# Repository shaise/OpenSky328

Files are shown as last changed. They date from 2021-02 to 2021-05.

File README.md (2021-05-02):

# OpenSky328
An atmel implementation of OpenSky FrSky-compatible RX  
Based on https://github.com/fishpepper/OpenSky

## Description
This open project aims to develop a family of small rc receivers compatibe with FR-Sky with telemetry.
List of devices:
* FR-8: An 8 channel PWM receiver with 2 analog telemetry inputs.
* FR-Tiny: A 5 channel micro receiver with brushed motor ESC, for micro rc planes. Weights just 2 grams.
* FR-LVH: A 1S land vehicle version with 2 bidirectional brushed motor esc (ch:1,2) and 2 servos (ch:3,4).
* Programmer adapter: Lets you connect above devices to a USBASP programmer, and USB-SERIAL adapter
The hardware is based on Atmega 328p microcontroller and TI CC2500 transceiver. 
The firmware is based on OpenSky FrSky-compatible receiver: https://github.com/fishpepper/OpenSky
It is also arduino based.

## 1. FR-8
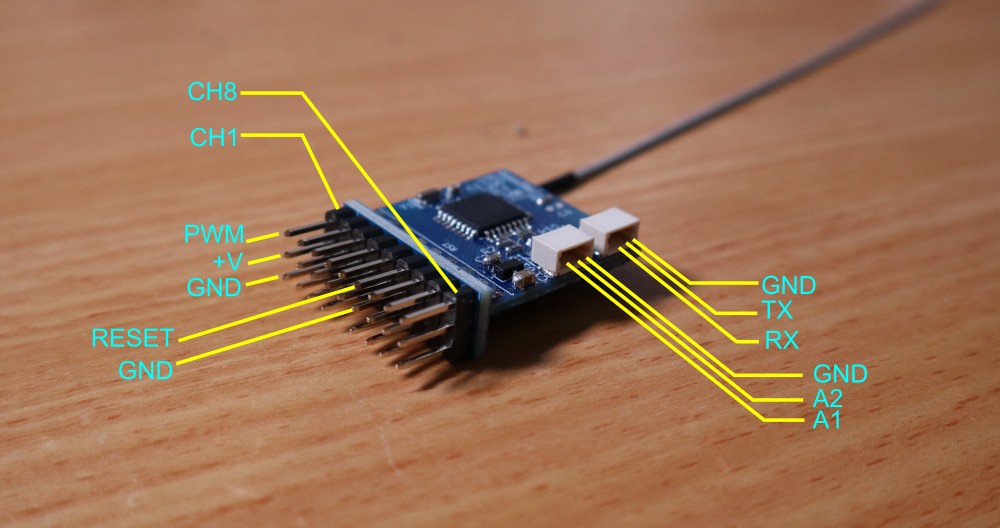
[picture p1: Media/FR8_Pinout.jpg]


## 2. FR-Tiny
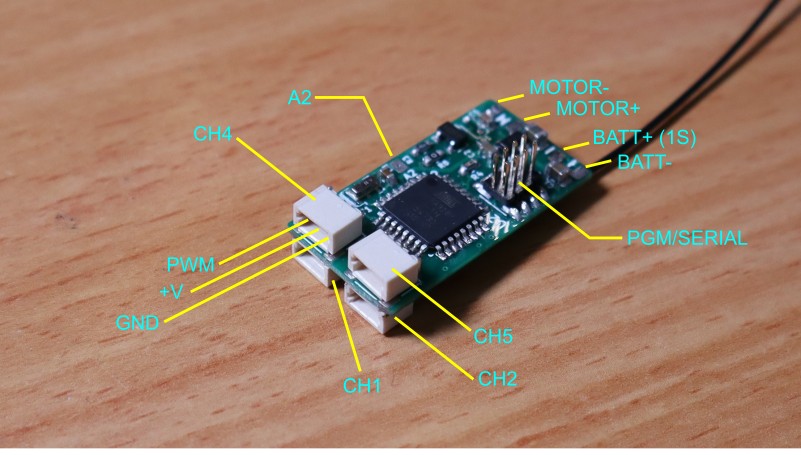
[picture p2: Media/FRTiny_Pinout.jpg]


## 3. FR-LVH
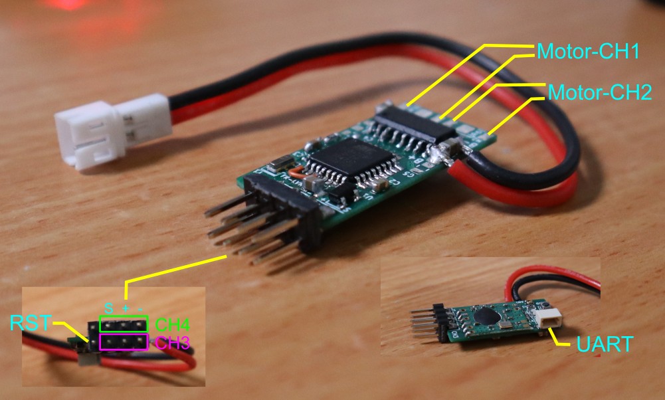
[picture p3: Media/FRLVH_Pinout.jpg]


## 4. FR-Pgm programmer
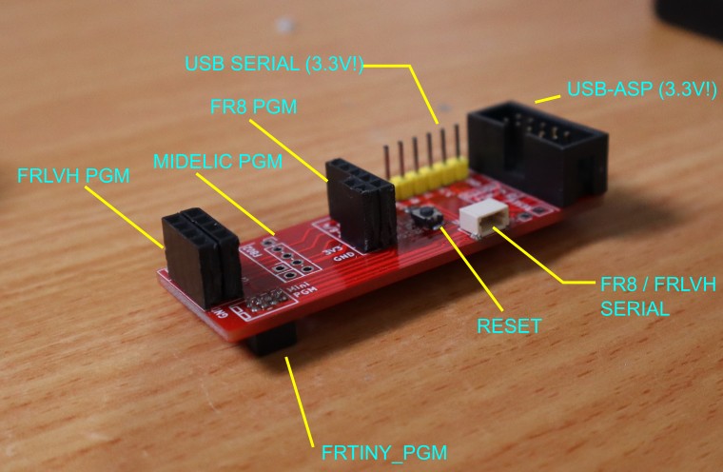
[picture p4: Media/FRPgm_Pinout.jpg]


## Assembling instructions

* Order the PCB by sending the gerbrt files to a manufacturer of your choice. I recommend [JLCPCB](https://jlcpcb.com/).
  * [FR-8 gerber files](/Release/gerbers_fr8_V1_2Layer_FR4_1.6mm.zip) and [FR-8 pins gerber files](/Release/gerbers_frmini8_pins_V1_2Layer_FR4_1.6mm.zip)
  * [FR-Tiny](/Release/gerbers_frtiny_V5_4Layer_FR4_1.0mm.zip)
  * [FR-LVH](/Release/gerbers_frlvh_V2_SWPWM_4Layer_FR4_1.0mm.zip)
  * [FR-Pgm](/Release/gerbers_frmini_prog_V4_2Layer_FR4_1.6mm.zip)
* Order all parts as listed in the BOM file. You will need a 0603 kit of resistors and capacitors, and for all other parts you will find a link in the BOM.
  * [FR-8 BOM](/Release/FR8_bom.pdf)
  * [FR-Tiny BOM](/Release/FRTiny.pdf)
  * [FR-LVH BOM](/Release/FRLVH_bom.pdf)
  * [FR-Pgm BOM](/Release/FRReceiverProg.pdf)
* Solder all parts. You can use the interactive BOM to assist you.
  * [FR-8 Interactive BOM](https://htmlpreview.github.io/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)
  * [FR-Tiny Interactive BOM](https://htmlpreview.github.io/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)
  * [FR-LVH Interactive BOM](https://htmlpreview.github.io/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)
  * [FR-Pgm Interactive BOM](https://htmlpreview.github.io/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)

 ## Programming the firmware
* Clone or download this repository.
* Edit config.h file and set the correct PCB version by uncommenting the correct line:  

Comment | Board support  
--- | ---  
#define RXBOARD_FR8_FRTINY | FR-8 or FR-Tiny boards  
#define RXBOARD_FRLVH | FR-LVH land vehicle boards  
* You will need a USBASB compatible programmer and either the programmin adapter above (recomended) or connect your own wires.
* NOTE!!! USBASP must be 3.3V version or you risk damaging the receiver.
* The software is arduino compatible (Arduino nano), so it should work with the Arduino IDE, however I did not test that. Instead I recommend using the [VS Studio Code IDE](https://code.visualstudio.com). You will need to install the C/C++ Addon, and the Platform IO addon (from the addon menu). Within Platform IO install the Atmel AVR platform.
* Connect the built receiver to the programmer using the adapter as follows:  
For FR-8:  
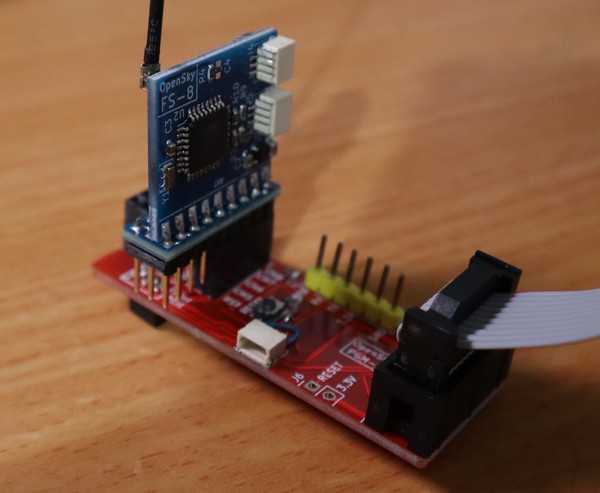
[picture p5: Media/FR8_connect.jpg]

  
For FR-Tiny:  
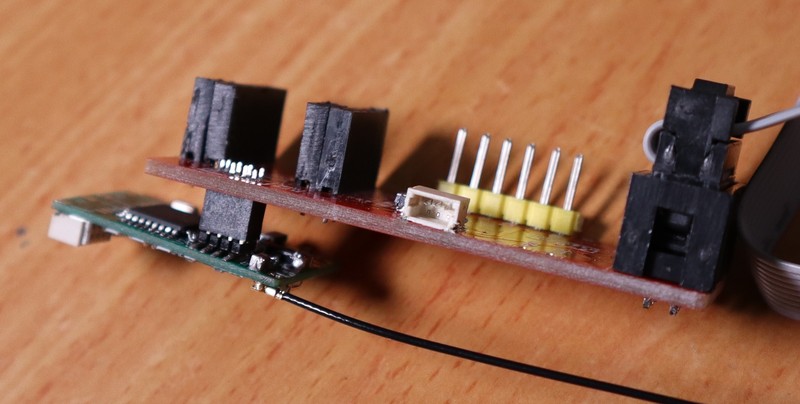
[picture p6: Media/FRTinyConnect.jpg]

  
For FR-LVH:  
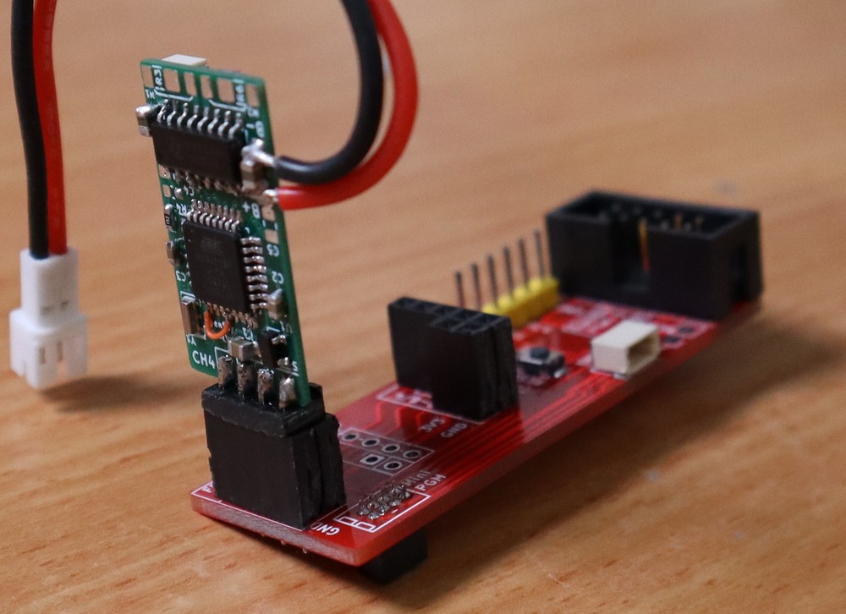
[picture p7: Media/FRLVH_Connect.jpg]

  
* Now open the 'Software' folder within VS Code. If you get a mesage that a workspace was detected, go ahead and press the "open workspace" button.
* On the left, click the PlatformIO icon (bug head), and from the "Project Tasks" menu, click the "Set fuses" line (should be under nanoatmega328->Platform). If everything is connected correctly, the Microcontroller fuses will be programmed.
* Now just press the 'PlatformIO: Upload" button at the bottom (the right arrow) and thats it!

## Usage
These receivers works with FR-Sky telemetry compatible transmitters (D8). (SW 1 and 2 off on DJT modules)
### Binding
You first need to bind the receiver with the transmitter (this is a one-time operation, repeat only if you change transmitter):  
* Press and hold the bind button and then powerup the receiver. Wait for the green light to turn on.
* Start binding procedure in your transmitter. If you are using an external module such as the DJT, Press and hold the module bind button and turn on the transmitter. 
* Wait for the red led on the receiver to start blinking. When it does, binding is complete! Turn off the transmitter and remove the receiver battery.
### Setting Fail safe
turn the tranmitter on then the receiver. Wait for the receiver green light to turn on. Press and hold the Bind button on the receiver for about 5 seconds till the red led turn on. Release the button, the red led will start blinking. You now have 10 seconds to set your fail safe state using the transmitter. When the time is up, the receiver will lock this state as the failsafe mode, and restart. when the green light is on again (without the red) the process is complete. This method of setting the fail safe mode is better then the standard, since you have both hands free to move the sticks to the desired state.
### Serial debugging
If you want to debug the receiver operation, you can use a serial terminal (built in VS code) to observe the debug data sent from the receiver.  
* Use a USB to serial Adapter. If you want to use the USB-serial to power the module, Make sure its a 3.3V version, or you risk damaging the modules.
* Connect the USB-Serial adapter to the programming adapter using the marked pins.
* Connect the programming adapter to the module as explained in the programming section.
* For the FR-Tiny you are all set. For the FR-8 / FR-LVH you will need an extra cable (jst to jst 1.0 mm 3pin) to connect the module to the serial input:  
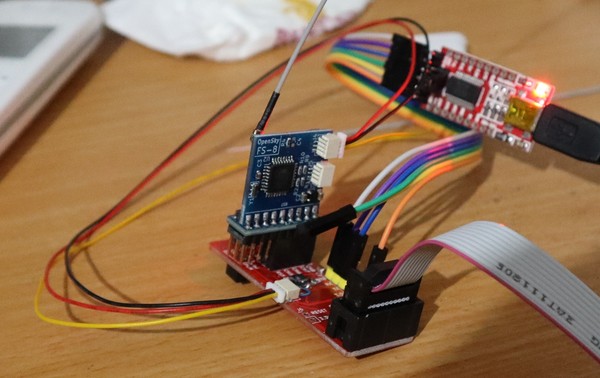
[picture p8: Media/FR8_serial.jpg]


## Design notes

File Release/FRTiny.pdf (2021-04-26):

Sheet1

Page 1

| Qty | References | Value | Footprint | Sourced
1 | 2 C3, C5 | | 100n_0603 | C_0603
2 | 1 C2 | | 22u_0603 | C_0603
3 | 1 C1 | | 4u7_0805_16V | C_0805
4 | 1 C4 | | 47u_0805 | C_0805
5 | 3 R2, R8, R10 | | 5K_0603 | R_0603
6 | 3 R4, R5, R7 | | 1K_0603 | R_0603
7 | 2 R1, R9 | | 22K_0603 | R_0603
8 | 1 R3 | | 0R_0603 | R_0603
9 | 1 D2 | | GREEN | LED_0603 | https://www.aliexpress.com/item/593098807.html
10 | 1 D3 | | RED | LED_0603 | https://www.aliexpress.com/item/593098807.html
11 | 1 U3 | | CC2500_MOD6 | CC2500_MOD6 | Std module: https://www.aliexpress.com/item/32246990983.html
12 | 1 U2 | | ATmega328P-MU | LQFP-32_7x7mm_P0.8mm | https://www.aliexpress.com/item/32213838233.html
13 | 1 U1 | | MCP1700 | SOT-23 | https://www.aliexpress.com/item/32995491794.html
14 | 1 Y1 | | CSTE16M | Res_SMD_3.0x1.3mm | https://www.aliexpress.com/item/2035036982.html
15 | 1 SW1 | | SW_BIND | SW_SPST_B3U-1000P | https://www.aliexpress.com/item/32623923874.html
16 | 1 AE1 | | Antenna_Shield | Conn_IPEX4 | https://www.aliexpress.com/item/10000166852637.html
17 | 1 Q1 | | Q_NMOS_GSD | SOT-23 | https://www.aliexpress.com/item/32983842840.html
18 | 4 J4, J5, J6, J7 | | JST1.0 | JST_SH_SM03B-SRSS-TB_1x03-1MP_P1.00mm_Horizont al | https://www.aliexpress.com/item/32819231540.html
19 | 1 J3 | | Conn_02x04_1.27 | PinHeader_2x04_P1.27m m_Vertical_SMD | https://www.aliexpress.com/item/4001224515002.html

None Pcb parts:
IPEX 4 antenna: | https://www.aliexpress.com/item/32990042506.html

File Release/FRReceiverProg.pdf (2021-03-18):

Sheet1

Page 1

| Qty | References | Value | Footprint | Sourced
1 | 2 | C1, C2 | 100n_0603 | C_0603_1608Metric
2 | 1 | SW1 | SW_Push | SW_SPST_4x3 | https://www.aliexpress.com/item/1005001412157463.html
3 | 1 | J3 | Conn_02x05 | IDC-Header_2x05_P2.54mm_Vertical | https://www.aliexpress.com/item/868008295.html
4 | 1 | J7 | Conn_01x03 | JST_SH_SM03B-SRSS-TB_1x03-1MP_P1.00mm_Horizontal | https://www.aliexpress.com/item/32819231540.html
5 | 1 | J6 | Conn_01x02 | PinHeader_1x02_P2.54mm_Vertical | cut to length https://www.aliexpress.com/item/32993182990.html
6 | 1 | J5 | Conn_01x06 | PinHeader_1x06_P2.54mm_Vertical | cut to length https://www.aliexpress.com/item/32993182990.html
7 | 2 | J4, J9 | Conn_01x02 | PinSocket_1x02_P2.54mm_Vertical | https://www.aliexpress.com/item/32863474581.html
8 | 2 | J1, J8 | Conn_01x05 | PinSocket_1x05_P2.54mm_Vertical | https://www.aliexpress.com/item/32667248348.html
9 | 1 | J2 | Conn_02x04 | PinSocket_2x04_P1.27mm_Vertical | https://www.aliexpress.com/item/4000960160661.html

Non PCB parts:
USB Serial adaprer: | Set to 3.3V! | https://www.aliexpress.com/item/33037470874.html
USBASP programmer: | Set to 3.3V! | https://www.aliexpress.com/item/32647598702.html
Serial jumper cable: | Select 3 pin double head | https://www.aliexpress.com/item/1005001303141070.html

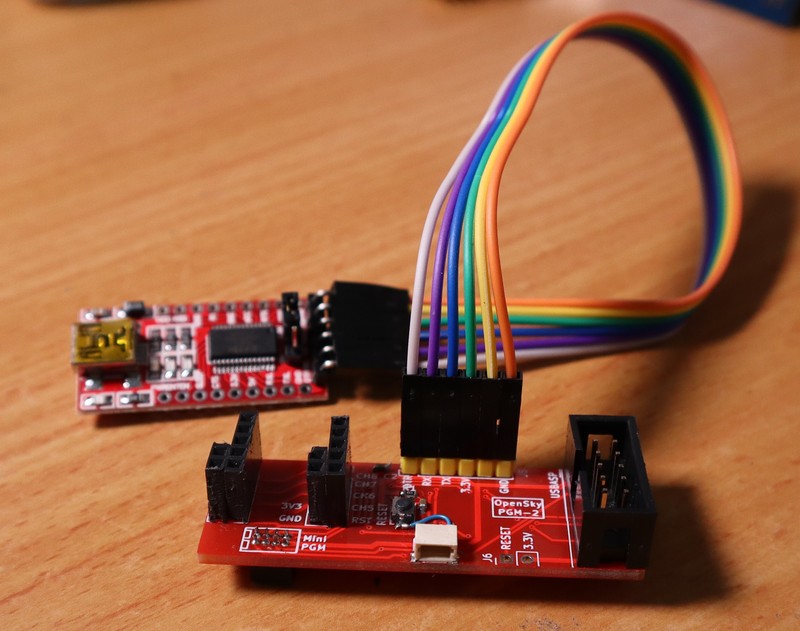
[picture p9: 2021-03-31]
Media/FRPgm_Serial.jpg

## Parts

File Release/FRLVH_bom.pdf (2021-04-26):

Sheet1

1 | 1 C2 | 22u_0603 | C_0603_1608Metric
2 | 1 C3 | 100n_0603 | C_0603_1608Metric
3 | 1 C4 | dns_0603 | C_0603_1608Metric
4 | 4 C5, C6, C7, C8 | 47u_0805 | C_0805_2012Metric
5 | 1 C1 | 4u7_0805_16V | C_0805_2012Metric
6 | 3 R4, R5, R7 | 1K_0603 | R_0603_1608Metric
7 | 1 R1 | 22K_0603 | R_0603_1608Metric
8 | 1 R2 | 5K_0603 | R_0603_1608Metric
9 | 2 R3, R6 | 10R_2512 | R_1206_3216Metric
10 | 1 D2 | GREEN | LED_0603_1608Metric
11 | 1 D3 | RED | LED_0603_1608Metric
12 | 1 U3 | CC2500_MOD6 | CC2500_MOD6
13 | 1 U4 | MX1508/MX1616 | SOIC-16
14 | 1 U1 | MCP1700 | SOT-23
15 | 1 U2 | ATmega328P-AU | TQFP-32_7x7mm_P0.8mm
16 | 1 Y1 | CSTE16M | Resonator_SMD_3.0x1.3mm
17 | 1 SW1 | SW_BIND | SW_SPST_B3U-1000P
18 | 1 AE1 | Antenna_Shield | Conn_IPEX4
26 | 1 J4 | JST1.0 | JST_SH_1x03- 1MP_P1.00mm_Horizontal

Sheet1

https://www.aliexpress.com/item/593098807.htmlhttps://www.aliexpress.com/item/593098807.html

https://www.aliexpress.com/item/4000426470690.htmlhttps://www.aliexpress.com/item/32995491794.htmlhttps://www.aliexpress.com/item/32213838233.htmlhttps://www.aliexpr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

https://www.aliexpress.com/item/32819231540.html

Std module: https://www.aliexpress.com/item/32246990983.html

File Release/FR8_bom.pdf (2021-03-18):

Sheet1

Page 1

| Quantity | References | Value | Footprint | Sourced
1 | 1 C2 | | 22u_0603 | C_0603
2 | 1 C3 | | 100n_0603 | C_0603
3 | 1 C4 | | dns_0603 | C_0603
4 | 1 C1 | | 4u7_0805_16V | C_0805
5 | 3 R4, R5, R7 | | 1K_0603 | R_0603
6 | 2 R1, R9 | | 22K_0603 | R_0603
7 | 2 R2, R10 | | 5K_0603 | R_0603
8 | 1 D2 | | GREEN | LED_0603 | https://www.aliexpress.com/item/593098807.html
9 | 1 D3 | | RED | LED_0603 | https://www.aliexpress.com/item/593098807.html
10 | 1 U3 | | CC2500_MOD6 | CC2500_MOD6 | Std module: https://www.aliexpress.com/item/32246990983.html
11 | 1 U4 | | CC2500_MOD6_PA | CC2500_MOD6_PA | Long range module: https://www.aliexpress.com/item/32810257490.html
12 | 1 U1 | | MCP1700 | SOT-23 | https://www.aliexpress.com/item/32995491794.html
13 | 1 U2 | | ATmega328P-AU | TQFP-32_7x7mm_P0.8mm | https://www.aliexpress.com/item/32213838233.html
14 | 1 Y1 | | CSTE16M | Res_SMD_3.0x1.3mm | https://www.aliexpress.com/item/2035036982.html
15 | 1 SW1 | | SW_BIND | SW_SPST_4x3 | https://www.aliexpress.com/item/1005001412157463.html
16 | 2 AE1, AE2 | | Antenna_Shield | U.FL_Hirose_U.FL-R-SMT-1_Vertical | https://www.aliexpress.com/item/33059352910.html
18 | 2 J4, J5 | | JST1.0 3pin | JST_SH_SM03B-SRSS-TB_1x03-1MP_P1.00mm_Horizon tal | https://www.aliexpress.com/item/32819231540.html

None PCB parts:
Ufl IPEX1 antenna: | https://www.aliexpress.com/item/4000290422103.html

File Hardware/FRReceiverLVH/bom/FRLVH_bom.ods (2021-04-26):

1 | 1 | C2 | 22u_0603 | C_0603_1608Metric
2 | 1 | C3 | 100n_0603 | C_0603_1608Metric
3 | 1 | C4 | dns_0603 | C_0603_1608Metric
4 | 4 | C5, C6, C7, C8 | 47u_0805 | C_0805_2012Metric
5 | 1 | C1 | 4u7_0805_16V | C_0805_2012Metric
6 | 3 | R4, R5, R7 | 1K_0603 | R_0603_1608Metric
7 | 1 | R1 | 22K_0603 | R_0603_1608Metric
8 | 1 | R2 | 5K_0603 | R_0603_1608Metric
9 | 2 | R3, R6 | 10R_2512 | R_1206_3216Metric
10 | 1 | D2 | GREEN | LED_0603_1608Metric | https://www.aliexpress.com/item/593098807.html
11 | 1 | D3 | RED | LED_0603_1608Metric | https://www.aliexpress.com/item/593098807.html
12 | 1 | U3 | CC2500_MOD6 | CC2500_MOD6 | Std module: https://www.aliexpress.com/item/32246990983.html
13 | 1 | U4 | MX1508/MX1616 | SOIC-16 | https://www.aliexpress.com/item/4000426470690.html
14 | 1 | U1 | MCP1700 | SOT-23 | https://www.aliexpress.com/item/32995491794.html
15 | 1 | U2 | ATmega328P-AU | TQFP-32_7x7mm_P0.8mm | https://www.aliexpress.com/item/32213838233.html
16 | 1 | Y1 | CSTE16M | Resonator_SMD_3.0x1.3mm | https://www.aliexpress.com/item/2035036982.html
17 | 1 | SW1 | SW_BIND | SW_SPST_B3U-1000P | https://www.aliexpress.com/item/32623923874.html
18 | 1 | AE1 | Antenna_Shield | Conn_IPEX4 | https://www.aliexpress.com/item/10000166852637.html
26 | 1 | J4 | JST1.0 | JST_SH_1x03-1MP_P1.00mm_Horizontal | https://www.aliexpress.com/item/32819231540.html

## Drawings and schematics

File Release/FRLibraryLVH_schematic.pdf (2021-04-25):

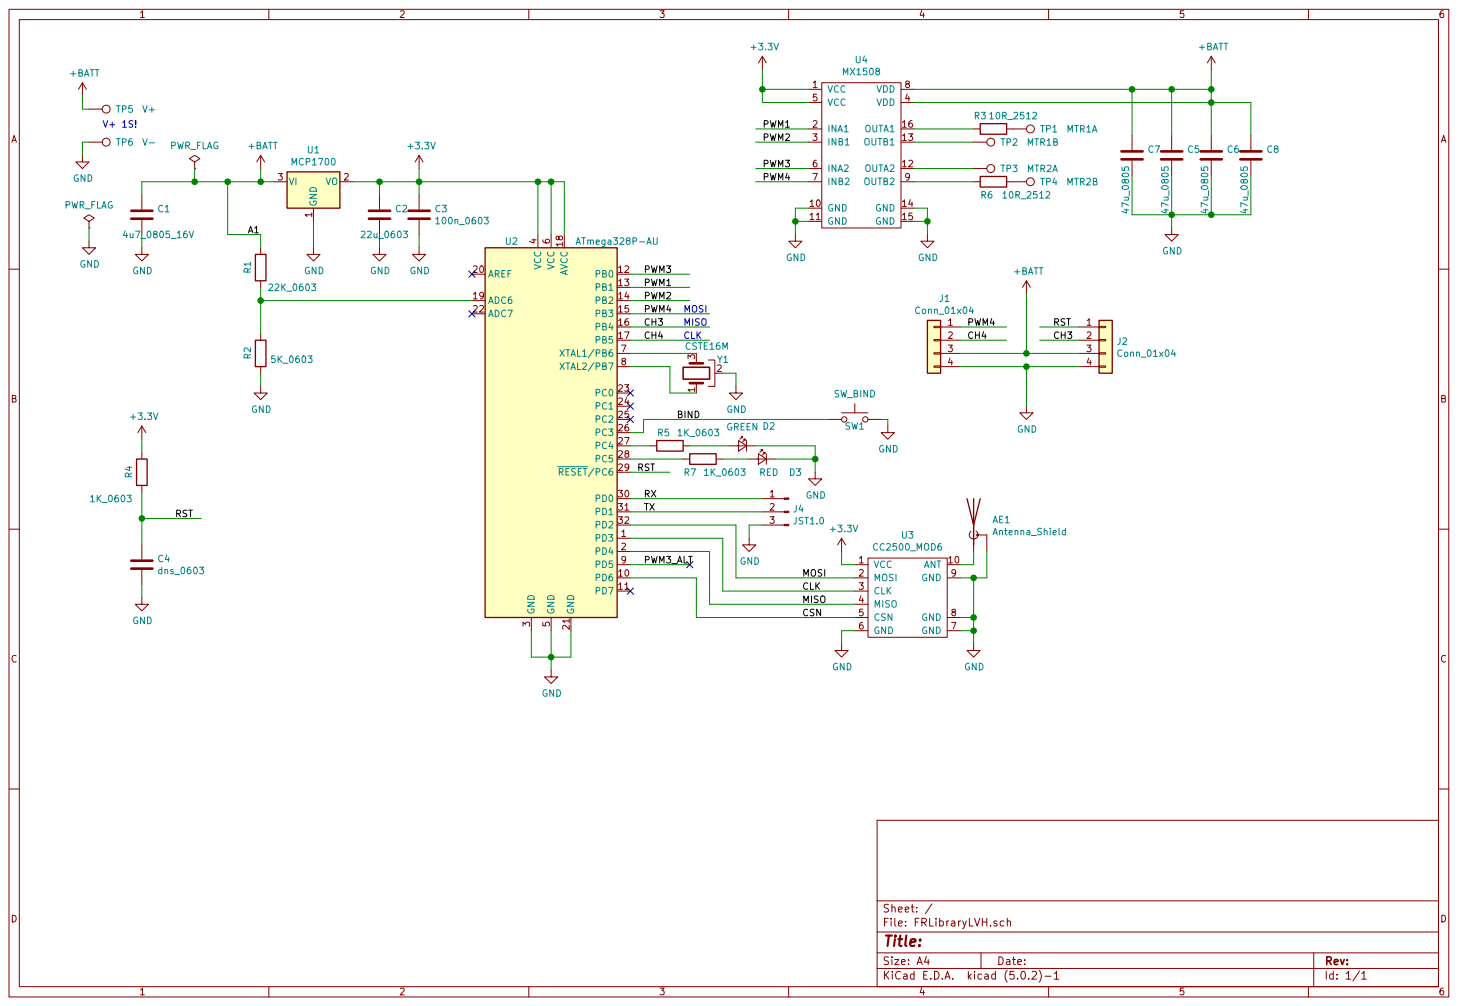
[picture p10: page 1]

1 VO 2 VI 3 U1 MCP1700 PD3 1 PD6 10 PD7 11 PB0 12 PB1 13 PB2 14 PB3 15 PB4 16 PB5 17 AVCC 18 ADC6 19 PD4 2 AREF 20 GND 21 ADC7 22 PC0 23 PC1 24 PC2 25 PC3 26 PC4 27 PC5 28 RESET/PC6 29 GND

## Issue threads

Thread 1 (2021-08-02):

Planning to make one but problem sourcing components.

saintofinternet, 2021-08-02:
Hello,

I am planning to make this as per your instructions but I am finding it difficult to source the components as per your list in Bill of Material.

What alternative do I have to carry out this work?

Regards,
-Siddharth

shaise, 2021-08-02:
Hi,

Please let me know which of the parts you can not find, and I will try to find another sorce.

shai

saintofinternet, 2021-08-04:
Hi, thank you very much for the reply.

I am having only one good source and that is www.element14.com

The BOM item names are not available on element14 when searched.

What alternative can be used?

-Siddharth

shaise, 2021-08-04:
Unfortunately not all parts can be sourced from element14.
Don't you have access to aliexpress?

saintofinternet, 2021-08-04:
aliexpress has been banned in my country.... :-(

are there alternatives to the components in BOM?

shaise, 2021-08-04:
I'm sorry about that, unfortunately I am not aware of any alternatives

stanekTM, 2021-08-04:
Hi, there must be an alternative, RS, Mouser, Farnell, Digi, ... [https://lcsc.com](url)

saintofinternet, 2021-08-05:
how about Digi-Key ?? they are available here.

shaise, 2021-08-05:
Hi,
Most parts can be found on digikey (albeit a bit expensive) but the most important part is the cc2500 module and can not be found there. Question: can you buy things from ebay?
https://www.ebay.com/itm/381876823225?hash=item58e9a1e4b9:g:xS0AAOSw4GVYR392

shai

saintofinternet, 2021-08-05:
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

Ebay closed down shop in India almost 6+ years ago... It's difficult to make anything in this country at times... :-) but I will surely make it.

Also regarding the BOM I have one query. When you mention  C2 value as 22u_0603 does it mean 22uF capacitor ?

now I am looking at the following sourcing options:

https://www.evelta.com
https://https://www.digikey.in

regards,
-Siddharth

saintofinternet, 2021-08-05:
>
>
> the big question is if they have the cc2500 modules. I doubt that.

This is available!

https://www.rhydolabz.com/wireless-general-c-130_131/cc2500-24ghz-transceiver-spi-interface-p-1201.html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

shaise, 2021-08-05:
>
> Also regarding the BOM I have one query. When you mention C2 value as 22u_0603 does it mean 22uF capacitor ?
>
Yes.

shaise, 2021-08-05:
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

It is compatible, but you will need to modify the pcb to use it (or connect the module with wires) also, it has a built-in antenna, so the range might be shorter.

saintofinternet, 2021-08-05:
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

I also have doubts about the internal RF antenna... so I am trying to see if I can get the 2500 PA module.

can you please clear the doubt about the C4 which says dns_0603 as it is not showing any results on searching!

shaise, 2021-08-05:
1. this module have also internal antenna but it is compatible with the pcb:
    https://www.robomart.com/2.4-ghz-rf-transceiver-cc2500?search=cc2500&dsearch=cc2500
2. C4 dns, means Do Not Solder (it is there for tests, but you dont need it)

saintofinternet, 2021-08-05:
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

Thank you very much for both the answers! Appreciate it!!! :-)

I will try to see other component sourcing from Digikey or Evelta as they are the only 2 options left with me now. :+1:

saintofinternet, 2021-08-29:
hi... still stuck with component sourcing unfortunately! :-(

glisandro, 2023-03-07:
Hi,
The link of the Q_NMOS_GSD mosfet no longer works, could you tell me if this https://ar.mouser.com/datasheet/2/268/20002092G-1218133.pdf is the same?

shaise, 2023-03-07:
> Hi, The link of the Q_NMOS_GSD mosfet no longer works, could you tell me if this https://ar.mouser.com/datasheet/2/268/20002092G-1218133.pdf is the same?

It should be at lease 5A mosfet such as AO3416: https://www.aliexpress.com/item/1005003648743765.html

glisandro, 2023-03-13:
Hi,
What is the secret for the crystal to work without capacitors? The selected crystal?

shaise, 2023-03-13:
It is not a crystal at all, it is a ceramic resonator. It does not require capacitors.

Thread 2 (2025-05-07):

Trying to upload the code to a chip outside the PCB

glisandro, 2025-05-07:
Hi,
I made a version on Arduino Nano, and it works very well. 💯

Now I want to test it on a TQFP32 to DIP28 adapter socket before soldering it to the PCB to make sure everything is correct, but it hasn't worked. I've disabled several chips, and I don't know exactly why... my knowledge is limited.

My question right now is this:

The resonator is 16MHz and the voltage is 3.3V, and in the documentation you warn against using 5V with USBASP because it could cause damage. But the AI   tells me this could be a problem, and reading the documentation for the ATMEGA328P, it recommends at least 4.5V for that frequency. I know you've built it and it works, but I'd like to understand this point.

Thanks.

shaise, 2025-05-09:
Sorry for not replying sooner. Happy that it worked!

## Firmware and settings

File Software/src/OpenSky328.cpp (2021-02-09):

/*
*/
//#include <SPI.h>
#include <Arduino.h>
#include <EEPROM.h>
const int dataReadyPin = 12;
const int chipSelectPin = 2;

extern "C" {
  #include "hal_debug.h"
  #include "hal_storage.h"
  #include "main.h"
  #include "hal_io.h"
  #include "hal_wdt.h"
  #include "hal_adc.h"
  #include "hal_soft_serial.h"
  #include "debug.h"
}

int main(void)
{
  init();
  //delay(5000);
  Serial.begin(115200);
  Serial.println("starting...\n");
  debug_init();
  opensky_main();
  return 0;
}

// hal commands

// debug
void hal_debug_start_transmission(uint8_t data)
{
  Serial.print((char)data);
}

void hal_debug_init(void) 
{
  Serial.println("hal debug init.\n");
}


// storage
void hal_storage_init(void)
{
  
}

void hal_storage_write(uint8_t *buffer, uint16_t len)
{
  for (uint32_t i = 0; i < len; i++)
  {
    EEPROM.write(i, *buffer);
    buffer++;
  }  
}

void hal_storage_read(uint8_t *storage_ptr, uint16_t len)
{
  for (uint32_t i = 0; i < len; i++)
  {
    *storage_ptr = EEPROM.read(i);
    storage_ptr++;
  }
}

// io
void hal_io_init(void)
{
  BIND_DIR &= ~BIND_PIN;
  BIND_OUT |= BIND_PIN; // make input pullup
  DEBUG_PIN_DIR |= (DEBUG_PIN_0 | DEBUG_PIN_1);
}

uint8_t hal_io_bind_request(void) 
{ 
  //Serial.println(BIND_PORT & BIND_PIN);
  return (BIND_IN & BIND_PIN) == 0; 
}

// watch dog
void hal_wdt_init(void) {}
void hal_wdt_reset(void) {}


// analog
void hal_adc_init(void) {}

uint8_t hal_adc_get_scaled(uint8_t ch)
{
  ch = ch == 0 ? ADC0_PIN : ADC1_PIN;
  return analogRead(ch) >> 2;
}
void hal_adc_process(void) {}

// soft serial
void hal_soft_serial_init(void) {}

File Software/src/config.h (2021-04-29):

#ifndef __PIN_CONFIG_H__
#define __PIN_CONFIG_H__
#include "main.h"

//#define RXBOARD_FR8_FRTINY
#define RXBOARD_FR4
//#define RXBOARD_FRLVH

/* TODO find correct pins for LEDs */
#define LED_RED_PIN (1 << 5)
#define LED_RED_OUT PORTC
#define LED_RED_DIR DDRC
#define LED_GREEN_PIN (1 << 4)
#define LED_GREEN_OUT PORTC
#define LED_GREEN_DIR DDRC

#define ADC0_PIN A6
#define ADC1_PIN A7

#define BIND_PIN (1 << 3)
#define BIND_OUT PORTC
#define BIND_IN PINC
#define BIND_DIR DDRC

#define DEBUG_PIN_0 (1 << 1)
#define DEBUG_PIN_1 (1 << 2)
#define DEBUG_PIN_DIR DDRC
#define DEBUG_PIN_OUT PORTC

// system supports only one of the following: PWM, SBUS, PPM

// enable SBUS output -> this will DISABLE ppm!
//#define SBUS_ENABLED
// Note: default/futaba is INVERTED=1! (use this for a cc3d etc)
//       inverted     => idle = LOW
//       non inverted => idle = high
#define SBUS_INVERTED

// PPM
// #define PPM_ENABLED
// invert SBUS output (normal is non inverted)
// #define PPM_INVERTED

// hub telemetry input (soft serial)
// #define HUB_TELEMETRY_ON_SBUS_UART
// #define HUB_TELEMETRY_INVERTED
// #define PPM_INVERTED

// PWM
#define PWM_ENABLED

// failsafe: bind button press time in ms the will initiate failsafe programming sequence
#define FAILSAFE_PRESS_TIME 50         // 5 seconds
#define FAILSAFE_PROGRAM_WAIT_TIME 100 // 10 seconds

// MOTOR - if enabled will output a pwm waveform based on selected channel, suitable for DC motors
#if defined(RXBOARD_FR8_FRTINY)
#define PWM_FIRST_CHANNEL 1
#define PWM_LAST_CHANNEL 8
#define MOTOR_ENABLED
#define MOTOR_CHANNEL 3
#define MOTOR_COUNT 1
#define HAL_MOTOR_PORT PORTC
#define HAL_MOTOR_PORT_DIR DDRC
#define HAL_MOTOR_PORT_MASKS \
    {                        \
        0X01                 \
    } // PORT C PIN 0
#elif defined(RXBOARD_FRLVH)
#define PWM_FIRST_CHANNEL 3
#define PWM_LAST_CHANNEL 4
#define MOTOR_ENABLED
#define MOTOR_CHANNEL 1
#define MOTOR_COUNT 2
#define MOTOR_BIDIR
#define MOTOR_ZERO 50    // % Position for 0 throttle
#define MOTOR_FREERUN 40 // % Position for motor freerun
#define MOTOR_BREAK 25   // % Position for motor break (motor reverse is 0 - motor break)
#define HAL_MOTOR_PORT PORTB
#define HAL_MOTOR_PORT_DIR DDRB
#define HAL_MOTOR_PORT_MASKS   \
    {                          \
        0X02, 0x04, 0x01, 0x08 \
    } // PORTB PINS (1 2),  (0 3)
#elif defined(RXBOARD_FR4)
#define PWM_FIRST_CHANNEL 1
#define PWM_LAST_CHANNEL 4
#endif

#define SBUS_USART USART1
#define SBUS_USART_CLK RCC_APB2Periph_USART1
#define SBUS_USART_RCC 2
#define SBUS_USART_GPIO GPIOA
#define SBUS_USART_GPIO_CLK RCC_APB2Periph_GPIOA
#define SBUS_USART_GPIO_CLK_RCC 2
#define SBUS_USART_TX_PIN GPIO_Pin_9
#define SBUS_USART_IRQHANDLER USART1_IRQHandler
#define SBUS_USART_IRQn USART1_IRQn

#define USE_SOFTWARE_SPI

#ifdef RXBOARD_FROLD
#define CC25XX_SPI_SCK_PIN (1 << 5)
#define CC25XX_SPI_SCK_OUT PORTB
#define CC25XX_SPI_SCK_DIR DDRB

#define CC25XX_SPI_MOSI_PIN (1 << 3)
#define CC25XX_SPI_MOSI_OUT PORTB
#define CC25XX_SPI_MOSI_DIR DDRB

#define CC25XX_SPI_MISO_PIN (1 << 4)
#define CC25XX_SPI_MISO_OUT PORTB
#define CC25XX_SPI_MISO_IN PINB
#define CC25XX_SPI_MISO_DIR DDRB

#define CC25XX_SPI_CSN_PIN (1 << 2)
#define CC25XX_SPI_CSN_OUT PORTB
#define CC25XX_SPI_CSN_DIR DDRB
#else
#define CC25XX_SPI_SCK_PIN (1 << 3)
#define CC25XX_SPI_SCK_OUT PORTD
#define CC25XX_SPI_SCK_DIR DDRD

#define CC25XX_SPI_MOSI_PIN (1 << 2)
#define CC25XX_SPI_MOSI_OUT PORTD
#define CC25XX_SPI_MOSI_DIR DDRD

#define CC25XX_SPI_MISO_PIN (1 << 4)
#define CC25XX_SPI_MISO_OUT PORTD
#define CC25XX_SPI_MISO_IN PIND
#define CC25XX_SPI_MISO_DIR DDRD

#ifdef RXBOARD_FRLVH
#define CC25XX_SPI_CSN_PIN (1 << 6)
#else
#define CC25XX_SPI_CSN_PIN (1 << 5)
#endif
#define CC25XX_SPI_CSN_OUT PORTD
#define CC25XX_SPI_CSN_DIR DDRD
#endif // FR_OLD

#define CC25XX_SPI_GDO1_PIN CC25XX_SPI_MISO_PIN
#define CC25XX_SPI_GDO1_IN CC25XX_SPI_MISO_IN
#define CC25XX_SPI_GDO1_DIR CC25XX_SPI_MISO_DIR

/* 
    XSR uses the Skyworks SE2431 range extender
    See: http:// www.skyworksinc.com/uploads/documents/SE2431L_202410J.pdf

    Looks to be a similar design to this: http:// www.ti.com/tool/CC2530-SE2431L

    Which means the RX pin selection is not needed (it is RX if TX is off)

    Either ANT can be used for both RX and TX.

    High is logic 1, Low is logic 0

    ANT (PB5) selection is 0 (left) or 1 (right)
    CTX (PA15) is 0 then RX LNA mode active, or 1 then tx mode
    CPS (PB3) is 0 then bypass mode is active, 1 is bypass off.
    CSD (PB4) with 1 to enable chip (0 = sleep)
*/

/* TODO revisit base on the above */
#define CC25XX_ANT_SW_CTX_GPIO GPIOC
#define CC25XX_ANT_SW_CTX_GPIO_CLK RCC_APB2Periph_GPIOC
#define CC25XX_ANT_SW_CTX_GPIO_CLK_RCC 2
#define CC25XX_ANT_SW_CTX_PIN GPIO_Pin_15

#define CC25XX_ANT_SW_CRX_GPIO GPIOC
#define CC25XX_ANT_SW_CRX_GPIO_CLK RCC_APB2Periph_GPIOC
#define CC25XX_ANT_SW_CRX_GPIO_CLK_RCC 2
#define CC25XX_ANT_SW_CRX_PIN GPIO_Pin_14
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

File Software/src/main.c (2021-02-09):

/*
    Copyright 2017 fishpepper <AT> gmail.com

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
   author: fishpepper <AT> gmail.com
*/

#include "led.h"
#include "io.h"
#include "debug.h"
#include "clocksource.h"
#include "timeout.h"
#include "delay.h"
#include "wdt.h"
#include "frsky.h"
#include "adc.h"
#include "storage.h"
#include "failsafe.h"
#include "telemetry.h"
#include "soft_serial.h"
#include "motor.h"

int opensky_main(void) {
    // leds:
    led_init();

    // init clock sources:
    clocksource_init();

    // init ios
    io_init();

    // init debug
    debug_init();

    // init wdt timer
    wdt_init();

    // enable timeout routines
    timeout_init();

    // init storage
    storage_init();

    // init frsky core
    frsky_init();

    // init adc
    adc_init();

    // init output
    sbus_init();
    ppm_init();
    pwm_init();
    motor_init();

    // init failsafe
    failsafe_init();

    // init telemetry
    telemetry_init();

    // run main
    debug("main: init done\n");

    // frsky_frame_sniffer();
    frsky_main();

    debug("main: frsky main ended?! THIS SHOULD NOT HAPPEN!");
    while (1) {}
}

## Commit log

2021-02-10 add pcbs
    [FRReceiver8.kicad_pcb, FRReceiver8.sch, FRReceiverProg.kicad_pcb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]
2021-03-17 add pcb files
    [FRReceiver8.kicad_pcb, FRReceiverPins.kicad_pcb, FRReceiverPins.sch]
2021-03-18 add bom
    [FR8_bom.ods, FRReceiverProg.ods, FRTiny.ods]
2021-03-18 add bom to release folder
2021-03-18 Update bom
2021-03-18 update bom page layout
    [FR8_bom.ods, FRReceiverProg.ods, FRTiny.ods]
2021-04-25 support FRLVH board
    [FRReceiverProg.kicad_pcb, FRReceiverProg.sch]
2021-04-25 Add land vehicle RX PCB
    [FRLibraryLVH.kicad_pcb, FRLibraryLVH.sch]
2021-04-25 Support bidirectional and multi motor drivers
2021-04-26 add FRLVH bom
    [FRLVH_bom.ods]
2021-04-26 add missing link
    [FRTiny.ods]
2021-04-26 rename misspelled files
    [FRReceiverLVH.kicad_pcb, FRReceiverLVH.sch]
2021-04-26 add frlvh bom to release
2021-04-29 add FR-4 pcb
    [FRReceiver4.kicad_pcb, FRReceiver4.sch]

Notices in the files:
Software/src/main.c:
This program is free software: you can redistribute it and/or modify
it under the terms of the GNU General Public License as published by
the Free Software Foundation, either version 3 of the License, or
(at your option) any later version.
